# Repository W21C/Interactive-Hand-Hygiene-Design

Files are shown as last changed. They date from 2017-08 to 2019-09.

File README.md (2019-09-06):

2019-09-06: This repository is no-longer being updated, and is out dated. A new more comprehensive version has been released September 2019.

# Interactive Hand Hygiene Design

W21C: http://w21c.org/

ECUAD: http://research.ecuad.ca/healthdesignlab/

## Project Background

This repository contains the hardware and software specifications neccesary to retrofit hand hygiene dispensers to capture real-time, continuous data and display that information with interactive design.  

## Collaboration

Emily Carr University of Art + Design's Health Design Lab developed the original software and hardware to promote hand hygiene compliance through interaction design in collaboration with Vancouver Coastal Health. W21C leveraged the existing technology, and modified the hardware to create networked hand hygiene dispensers to implement onto a medical teaching unit at Foothills Medical Center (Calgary, Alberta), with the goal of promoting hand hygiene compliance. 

## Tech Details

The most recent W21C project uses Xbees embedded into hand hygiene dispensers to track usage of hand hygiene dispensers on a hospital unit. The Xbees communicate with a Processing sketch via an arduino and serial communication.

Software Folder: Processing code for recording and visualizing dispenser use.

Hardware Folder: Specifications for networked hand hygiene dispensers using Xbees and Arduinos, as well as a parts list that includes video terminals and computing. 

## Impact and Efficacy

A Quality Improvement project by W21C at Foothills Medical Center produced results that indicate interaction design successfully increases hand hygiene compliance and that frequency of use of the modified hand hygiene dispensers correlates with hand hygiene compliance. 

## Objectives

Share and promote the improvement and dissemination of this freely available hardware and software, this social innovation demonstrates the potential to increase hand hygiene compliance and innovation in healthcare and everywhere else !

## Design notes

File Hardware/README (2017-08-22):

This folder contains the hardware specifications neccasary to retrofit hand hygiene dispensers for interaction design. 

Fritzing - Fritzing file for the schematic and PCB design

PCB schematics - PCB digram for Transmitters and Receivers for the XBee network

Functional Breakdown - support to build and install the modified hand hygiene dispensers

Parts list - all of the hardware components (i.e., Xbees, arduinos, batterypacks, CPU) used to build wirless Xbee networks 
and display the data on TV monitors. 

Xbee Migration - guide to  assist you with migrating from the XBee/XBee-PRO ZB (S2/S2B) to the XBee/XBee-PRO ZB
(S2C) Through-Hole modules.

Switch Integration - The switch used in the current version was plastered onto the hand hygiene dispenser with sugru. 
Our team would recommend creatively constructing an alternative to our 'switch and sugru' solution. Have fun !

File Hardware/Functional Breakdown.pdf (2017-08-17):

# Functional Decomposition Of Wireless Communication & Display

## Prepared by:

Manas Bhatnagar, MHSc
Based on work done by
Health Design Lab at the Emily Carr Design University

Version: 2.0 (release candidate) Last Updated: 18th Apr 2016

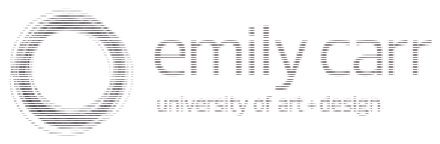
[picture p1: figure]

TV Display

# Concept Level

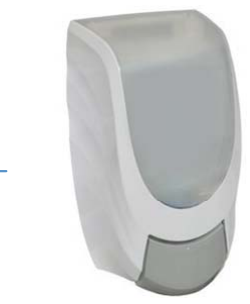
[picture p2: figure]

Mechanical Hand
Sanitizer Pump

# Level 0

Transmitter
(Tx) Receiver (Rx)

Mechanical
Hand Sanitizer
Pump

TV Display

# Level 1

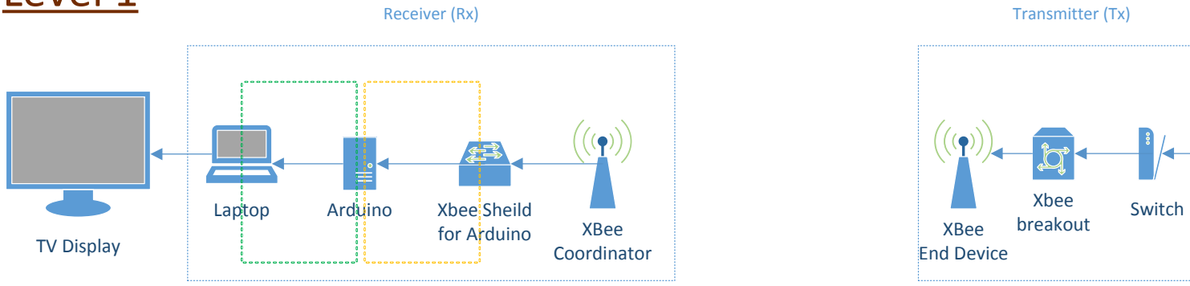
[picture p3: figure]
XBee Coordinator; Laptop; Arduino; TV Display; Xbee Sheild for Arduino; Switch; XBee End Device; Xbee breakout; Receiver (Rx); Transmitter (Tx)

Mechanical
Hand
Sanitizer
Pump

# Level 2 – Detailed Design

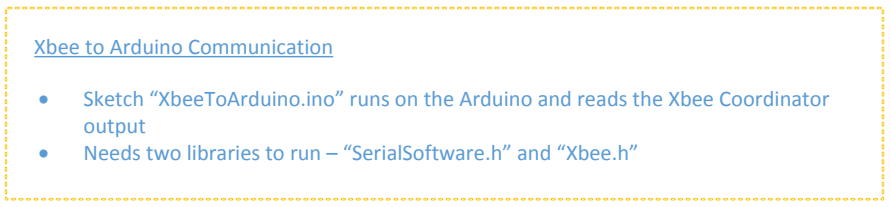
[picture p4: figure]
Xbee to Arduino Communication; output
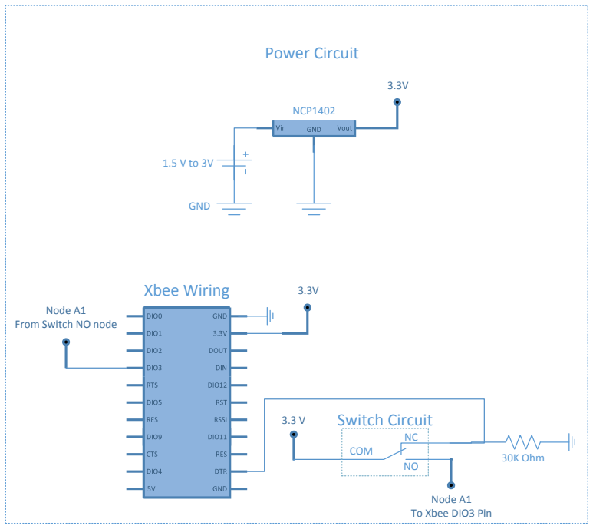
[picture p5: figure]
GND; NCP1402; Power Circuit; Switch Circuit; 30K Ohm; Node A1 To Xbee DIO3 Pin; Xbee Wiring; Node A1 From Switch NO node; COM

- Sketch “XbeeToArduino.ino” runs on the Arduino and reads the Xbee Coordinator
- Needs two libraries to run – “SerialSoftware.h” and “Xbee.h”

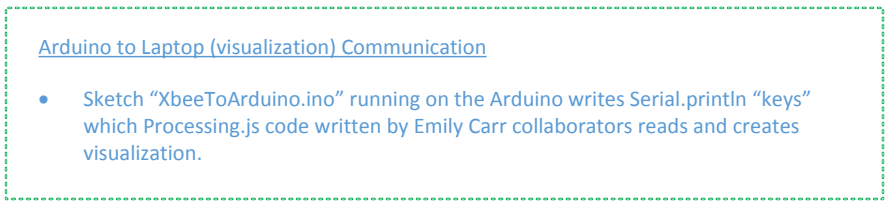
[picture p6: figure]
Arduino to Laptop (visualization) Communication; visualization.

- Sketch “XbeeToArduino.ino” running on the Arduino writes Serial.println “keys” which Processing.js code written by Emily Carr collaborators reads and creates

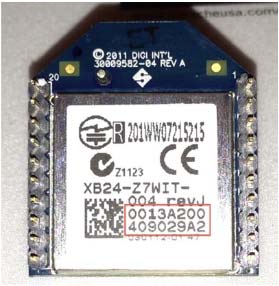
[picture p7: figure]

Figure 1

- Mount Xbee unit onto Explorer USB and connect to a PC via USB.
- Start the XCTU application. Click “Discover Devices” button in the top left corner.
- Click “Next”>”Finish”. Any connect devices should be displayed at this point. Click “Add selected devices”.
- If this is the first time this Xbee is being connected to a computer, then click the “Update firmware” icon. If this Xbee will be used at the receiving end, select “ZigBee Coordinator API”. Else if this Xbee will be used at the transmitting end, select “ZigBee End Device API”. Click “Update”
- Change “PAN ID” to a unique value. All Xbee’s on a network have the same Pan ID.
- If you are configuring an Xbee to be used at the transmitting end, then change the following values,

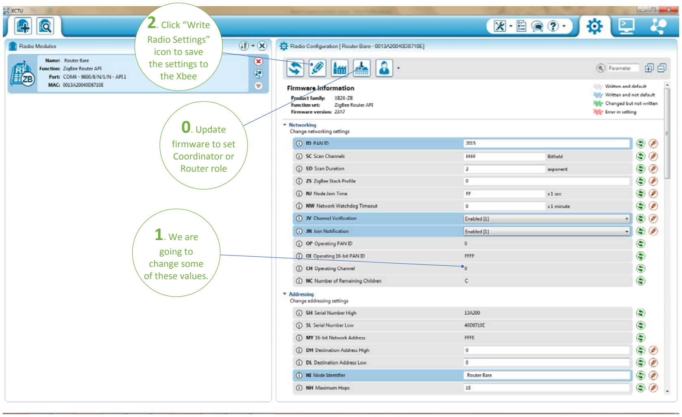
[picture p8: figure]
0. Update; firmware to set Coordinator or Router role; 1. We are; going to change some of these values.; 2. Click “Write; Radio Settings” icon to save the settings to the Xbee

- If you are configuring an Xbee to be used at the receiving end, then change the following values
- Click “Write Radio Settings” icon to save these setting to the Xbee.

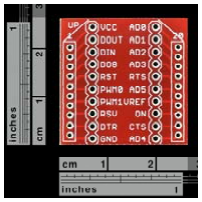
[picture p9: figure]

Figure 2

- Set “JN Join Notification” to Enabled
- Set “NI Node Identifier” to name this particular Xbee.
- Set “PL Power Level” to Lowest [0]
- Set “PM Power Mode” to Boost mode disabled [0]
- Set “SM Sleep Mode” to Pin Hibernate [1]
- Set “SP Cyclic Sleep Period” to AF0
- Set “SN Number of Cycles to power down IO” to FFFF
- Set “SO Sleep Options” to 4
- Set “D3 AD3/DIO3 Configuration” to ADC [2]
- Set “IR IO Sampling Rate” to 190. This makes the Xbee send its state every 400ms. Set it to 3E8 if you want the Xbee to send its state every second. Set it to 1F4 if you want the Xbee to send its state every half second. For other time intervals, use a decimal to hexadecimal calculator to convert time in milliseconds to its hexadecimal representation.
- Set “V+ Supply Voltage High Threshold” to FFFF
- Set “NI Node Identifier” to name this particular Xbee.
- Set “AP _________” to 2
- Set “SP Cyclic sleep period” to AF0
- Set “SN Number of Cycles to power down IO” to FFFF

# XBee

- Many types. We are using the “Xbee ZigBee (2 mW ‐PCB Antenna)” type.
- Each has a unique factory set ID (Figure 1). We need to note these down and identify the ones we configure as coordinators.
- The pins on the Xbee are too close together for prototyping and so we need to use a breakout board to work with it or read it using a USB. We are using the Sparkfun Breakout board for Xbee Module (Figure 2) for this purpose.
- Before the Xbee’s can be used in a network, we need to configure them ‐

# Arduino

- Many types. We are using the “Arduino Uno SMD Rev3” type.
- In addition to the Arduino IDE, you’ll need to ensure that the following libraries are installed in the Arduino IDE –
- Arduino code (“sketch”) XbeeToArduino the code that will need to be changes if any changes or additions are required.
- Once the code is changed, click “Verify” icon to ensure there are no errors.
- If the code successfully compiles, click the “Upload” icon to download the code to the arduino board. This code will run in a loop whenever the arduino has power.
- For troubleshooting, a lot of the commented code can be uncommented and its output can be viewed on the “Serial Monitor” in the Arduino IDE.

Adding a new Xbee to Arduino code so visualization can occur
- After the Xbee is configured appropriately (See section on Xbee), convert the last four digits of the Xbee’s address to decimal format: http://www.binaryhexconverter.com/hex‐to‐decimal‐converter
- Enter this decimal number into the swtich statement as a new case.
- Serial.println(“X”) ‘X’ can range from 1 to 6 depending on what colour of visualization you’d like.
- Compile the code. If Compilation is successful, upload the code to the Arduino.
- SoftwareSerial.h ‐ https://www.arduino.cc/en/Reference/SoftwareSerial
- XBee.h ‐ https://github.com/andrewrapp/xbee‐arduino

# Processing

- Processing.js creates the visualization. Our code runs on the Processing version 2.2.1. Newer versions are available, but I’m not confident that we will not face backwards compatibility issues.
- To change any aspect of the visualization, this is the code that must be changed.
- When any of the code is opened in the Processing IDE, many tabs are created. Relevant tabs might be “Serial” and “Handwashing”.
- Maintain the files/folder structure.
- The original Emily Carr code also does table creation and backend utilization counts. But my recommendation is to recreate all research tracking from scratch in the Arduino code.

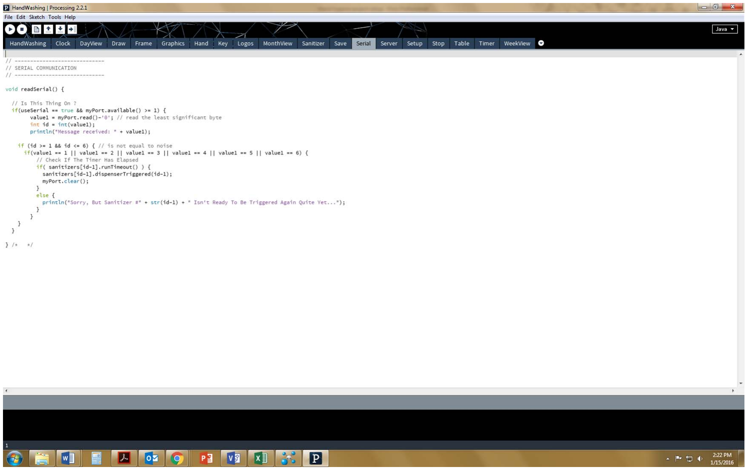
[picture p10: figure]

# Steps to set‐up code on a new computer

- Install Arduino IDE from: https://www.arduino.cc/en/Main/Software
- Once installation is over, start the Arduino IDE. Click Sketch>Include Library>Manage Libraries..
- Plug in the Arduino Board.
- Windows might look for device drivers if this is the first time an Arduino is being connected to the machine. Allow it to do so. It may take several minutes.
- Once device drivers are installed Windows will display a COM port associated with the Arduino. Ex: COM1, COM3, COM6 etc.
- Obtain a bright green USB named HndHygInstl. It contains most of the files needed to make the code run on another machine.
- Copy all the files from this USB on to the computer.
- Open folder “processing‐2.2.1” and run the processing application. If prompted to upgrade version, say no.
- Once the processing application has started (an empty sketch). Close it.
- Go to folder labeled ProcessingCode>Processing>HandWashing. Open file called Setup. (You might have to maximize the window size of the Processing IDE and find the Setup tab)
- In the “if(useSerial == true)” statement, in line 37, change the value of COM# to match the value you noted down from the device manager in previous steps.
- In the ‘Handwashing’ tab, change the Network_Name variable to the correct value, i.e. Network_201#
- Save these changes by clicking File>Save.
- Ensure the Arduino is plugged in. Then turn on a transmitter unit. And Run the Processing code by clicking the play button near the top left corner.
- If all is well, then you should see the black screen of the application start and you can test the system by using the transmitter to create a hand print on the screen
- If asked for permissions to install drivers, say yes.
- In the search bar type “Xbee” and install the Xbee‐Arduino Library by Andrew Rapp (You will need to be connected to the internet for this step)
- Next search for “SoftwareSerial” and ensure that it is installed
- If this is not shown, you can find this information by going to the Control Panel>Hardware and Sound>Device Manager
- Click ‘Ports’ and note the COM# associated with the Arduino board

# Versioning Convention

- 0 for alpha (status)
- 1 for beta (status)
- 2 for release candidate
- 3 for (final) release.

# To‐do List

- GitHub source control for all code
- Add flag for low battery
- Add code to track usage
- Add software filter to reduce false positives
- Periodic polling to ensure all devices are functioning

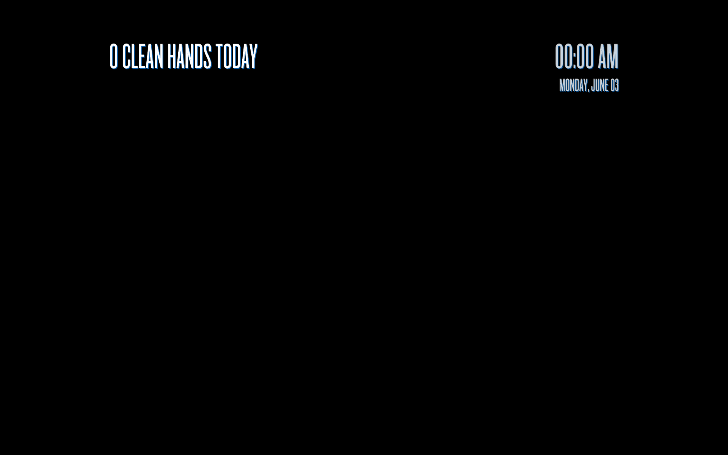
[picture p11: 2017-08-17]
Software/ProcessingCode/Processing/HandWashing/Screenshots/handproject_2013-6-4-0-0-30.PNG

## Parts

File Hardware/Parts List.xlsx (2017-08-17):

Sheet: QI Grant Budget
 | Parts List (per wing)
 |  | Part Name | Specification | Quantity | Price | Product URL
Power |  | AA rechargeable battery | 1.5V | 12 | 51 | Best-buy link (http://www.bestbuy.ca/en-CA/product/energizer-energizer-nh15bp4-4-pack-aa-nimh-rechargeable-batteries-aa-4-nimh/10019056.aspx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)
 |  | Battery holder |  | 6 | $7.74 | http://www.canadarobotix.com/battery-chargers/2-aa-battery-holder-enclosed-with-switch
 |  | 3.3V Transformer | 3.3V step up from 1v to 3V | 6 | $39.54 | http://www.canadarobotix.com/power-regulator/1235-pololu-3-3v-step-up-voltage-regulator-ncp1402 | https://www.sparkfun.com/products/10967
General |  | Headers | Male and Female | 5 | $6.75 | http://www.canadarobotix.com/cables-wires/parts-arduino-stackable-header-r3 http://www.canadarobotix.com/cables-wires/parts-header-female-straight-40 http://www.canadarobotix.com/cables-wires/parts-break-away-header-male-straight-40
 |  | Jumperwires | Red, black and one other colour | 1 | $6.99 | http://www.canadarobotix.com/cables-wires/1162-premium-splittable-jumper-wire-40-pins-m-f-20cm
 |  | Wire | Red, black and one other colour | 1 | $5.99 | http://www.canadarobotix.com/prototyping/140-piece-wire-kit
 |  | Wire Stripper |  | 1 | $15 | http://www.canadiantire.ca/en/pdp/mastercraft-calibrated-wire-stripper-0529938p.html#.Viax4X6rS70
 |  | Solder |  | 1 | $11 | http://www.thesource.ca/estore/Product.aspx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
 |  | Protoboard |  | 6 | $17.94 | http://www.canadarobotix.com/prototyping/1160-protoboard-3x7cm-2-sided
 |  | Breadboard |  | 1 | $4.99 | http://www.canadarobotix.com/solderless-breadboard/830-point-breadboard
 |  | Resistors | 10K Ohm | 6 | $3.54 | http://www.canadarobotix.com/electronic-components/10k-ohm-resistor-1-4w-5
 |  | LEDs |  | 1 | $4.99 | http://www.canadarobotix.com/led-lighting/1698-basic-3mm-led-25x-red
 |  | Plastic Casing |  | 7 | $70.00
 |  | Misc Shipping |  |  | $50.00
Sensors |  | Xbee-ZB | series 2 | 7 | $83.07 | http://www.canadarobotix.com/xbee/digi-xbee-zb-2mw-pcb | https://www.sparkfun.com/products/11217
 |  | Xbee Explorere USB |  | 6 | $197.34 | http://www.canadarobotix.com/xbee-adapters/1230-sparkfun-xbee-explorer-usb | https://www.sparkfun.com/products/11812
 |  | Arduino Uno | SMD R3 | 1 | $26.69 | http://www.canadarobotix.com/arduino-microcontroller/arduino-uno-smd-3 | https://www.sparkfun.com/products/11224
 |  | Sparkfun Xbee Sheild |  | 1 | $21 | https://www.sparkfun.com/products/12847
 |  | On-Off Switch |  | 6 | $24 | http://www.digikey.ca/product-search/en?keywords=SW1068-ND
Display |  | Small Laptop | Must have USB, Display out and decent graphics processor | 1 | $479 | http://www.dell.com/ca/p/inspiron-11-3157-laptop/pd?oc=ni113157_bt_h1403e&model_id=inspiron-11-3157-laptop
 |  | LCD display |  | 1 | $199 | http://www.bestbuy.ca/en-CA/product/insignia-insignia-32-720p-60hz-led-tv-ns-32d220na16-gloss-black-ns-32d220na16/10346767.aspx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
 |  | LCD Display Mount |  | 1 | $99 | http://www.bestbuy.ca/en-CA/product/tyger-claw-tygerclaw-17-37-full-motion-flat-panel-tv-wall-mount-lcd5004blk-lcd5004blk/10200518.aspx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
 |  | HDMI Cable |  | 1 | $4 | http://www.bestbuy.ca/en-ca/product/dynex-dynex-0-9m-3-ft-hdmi-cable-dx-sf115-dx-sf115/10238212.aspx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
 |  |  |  | Total: | $1428.57

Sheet: version 1 Build
 |  | Parts List
 |  |  | Part Name | Specification | Quantity | Price | Product URL
 | Power |  | AA battery | 1.5V | 2 per TXunit | $9.99 | http://www.bestbuy.ca/en-ca/product/energizer-energizer-aa-1-5v-8-pack-batteries-aa-8-pack/38771003.aspx
 |  |  | Battery holder |  | 1 per TX unit | $1.29 | http://www.canadarobotix.com/battery-chargers/2-aa-battery-holder-enclosed-with-switch
 |  |  | 3.3V Transformer | 3.3V step up from 1v to 3V | 1 per TX unit | $13.18 | https://www.sparkfun.com/products/10967 | http://www.canadarobotix.com/power-regulator/1235-pololu-3-3v-step-up-voltage-regulator-ncp1402
 | General |  | Headers | Male and Female | 3,1,1 | $6.75 | http://www.canadarobotix.com/cables-wires/parts-arduino-stackable-header-r3 http://www.canadarobotix.com/cables-wires/parts-header-female-straight-40 http://www.canadarobotix.com/cables-wires/parts-break-away-header-male-straight-40
 |  |  | Jumperwires | Red, black and one other colour | 1 | $6.99 | http://www.canadarobotix.com/cables-wires/1162-premium-splittable-jumper-wire-40-pins-m-f-20cm
 |  |  | Wire | Red, black and one other colour | 1 | $5.99 | http://www.canadarobotix.com/prototyping/140-piece-wire-kit
 |  |  | Protoboard |  | 1 per TX unit | $5.98 | http://www.canadarobotix.com/prototyping/1160-protoboard-3x7cm-2-sided
 |  |  | Resistors | 30K Ohm | 1 per TX unit | $0.15 | https://www.digikey.ca/product-detail/en/stackpole-electronics-inc/CF14JT30K0/CF14JT30K0CT-ND/1830386
 | Sensors |  | Xbee-ZB | series 2 | 2 | $55.38 | http://www.canadarobotix.com/xbee/digi-xbee-zb-2mw-pcb | https://www.sparkfun.com/products/11217 | NOTE: The S2 has been discontinued and is replaced by the S2C - http://ftp1.digi.com/support/documentation/XBee%20ZigBee%20Migration%20Guide.pdf
 |  |  | Xbee Explorere USB |  | 1 | $32.89 | http://www.canadarobotix.com/xbee-adapters/1230-sparkfun-xbee-explorer-usb | https://www.sparkfun.com/products/11812
 |  |  | Arduino Uno | SMD R3 | 1 | $26.69 | http://www.canadarobotix.com/arduino-microcontroller/arduino-uno-smd-3 | https://www.sparkfun.com/products/11224
 |  |  | Sparkfun Xbee Sheild |  | 1 | $21 | https://www.sparkfun.com/products/12847
 |  |  | Switch |  | 1 per TX unit | $4.5 | https://www.digikey.ca/product-detail/en/omron-electronics-inc-emc-div/SS-5GL2T/SW873-ND/369897
 | Display & Computing |  | Laptop or Computer |  | 1 | $350 | Requirements: USB, HDMI display out, Windows OS, decent graphics processor
 |  |  | LCD Display |  | 1 | $200 | Requirements: HDMI display input
 |  |  | LCD Display Mount |  | 1 | $25 | Wall mount
 |  |  | HDMI Cable |  | 1 | $25 | Length dependent on PC - Display distance
 | Tools |  | Wire Stripper |  | 1 | $14.99 | http://www.canadarobotix.com/soldering-tools/1892
 |  |  | Soldering Iron |  | 1 | $43.59 | http://www.canadarobotix.com/soldering-tools/1898
 |  |  | Solder |  | 1 | $10.59 | http://www.canadarobotix.com/soldering-tools/solder-lead-free-100-gram-spool
 |  |  | Sponge |  | 1 | 7.29 | http://www.canadarobotix.com/soldering-tools/2118
` |  |  | Voltmeter/Multimeter |  | 1 | $19.69 | http://www.canadarobotix.com/measurement-equipment/1476-sparkfun-digital-multimeter-basic
 |  |  | Breadboard |  | 1 | $3.99 | http://www.canadarobotix.com/solderless-breadboard/400-point-breadboard-standard
 |  |  |  |  | Total | 190.78

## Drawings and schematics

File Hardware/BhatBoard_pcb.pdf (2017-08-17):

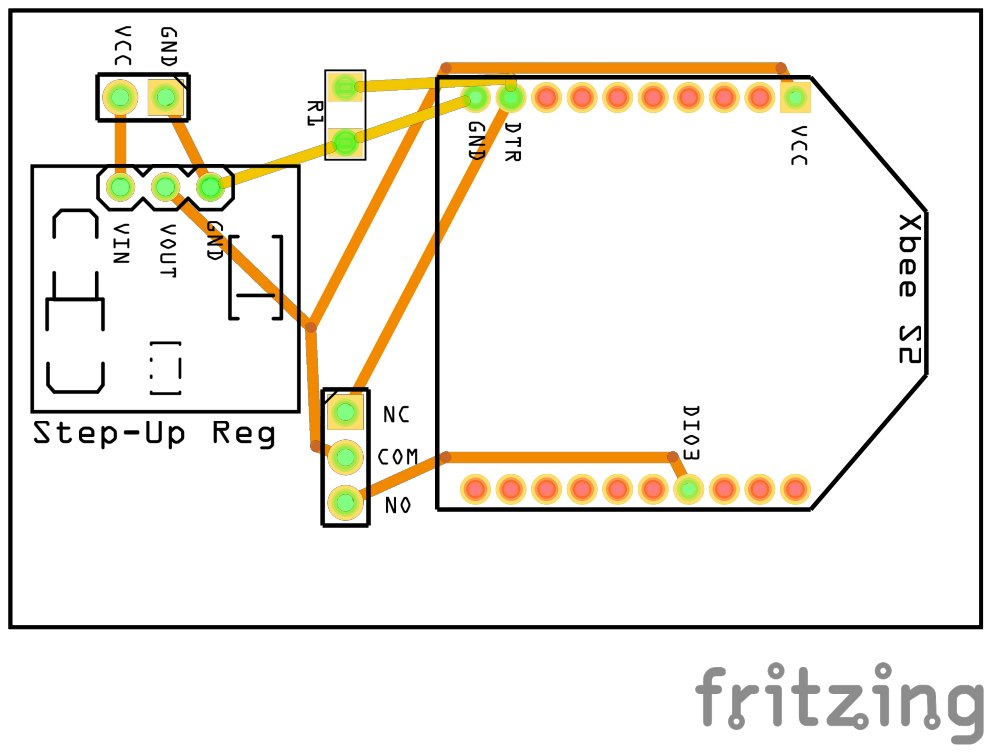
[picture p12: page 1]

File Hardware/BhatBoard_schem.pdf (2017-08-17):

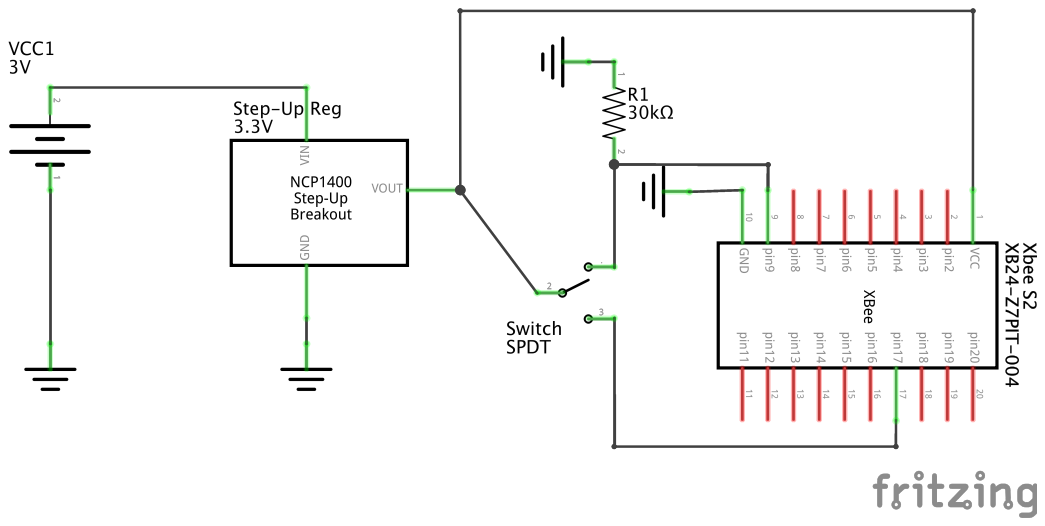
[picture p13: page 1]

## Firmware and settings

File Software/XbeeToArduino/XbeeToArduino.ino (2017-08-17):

#include <XBee.h>
#include <SoftwareSerial.h>

// Setup pin definitions for XBee shield
uint8_t recv = 2;
uint8_t trans = 3;
SoftwareSerial soft_serial(recv, trans);

// Instantiate an instance of the XBee library
XBee xbee = XBee();

// Instantiate an instance of the IO sample class
ZBRxIoSampleResponse ioSample = ZBRxIoSampleResponse();

void setup() {
  Serial.begin(9600);
  while (!Serial); // Leonardo boards need to wait for Serial to start
  soft_serial.begin(9600);
  xbee.setSerial(soft_serial);
}

// Get address and print it
void get_address(ZBRxIoSampleResponse *ioSample) {
//  Serial.print("Received data from address: ");
//  Serial.print(ioSample->getRemoteAddress64().getMsb(), HEX);
//  Serial.print(ioSample->getRemoteAddress64().getLsb(), HEX);
//  Serial.println("");
}

// Get voltage at signal pin DI03 and print it
void get_temperature(ZBRxIoSampleResponse *ioSample) {
  int Address_LSB = (ioSample->getRemoteAddress64().getLsb());
  String Address = String(Address_LSB, HEX);
     //Serial.print("Last four didgits of HEX Address: ");
     //Serial.print(Address); Serial.println(" ");
     //Serial.print("Decimal number to use in Switch Statement: ");
  //Serial.print(Address_LSB); Serial.println(" ");Serial.println(" ");
  //int Packet_length = (ioSample->getPacketLength());
  
  float adc_data = ioSample->getAnalog(3);
  float temperatureC = ((adc_data * 1200.0 / 1024.0) / 1000.0);
  
  int ref = xbee.getResponse().getFrameData()[17]<<8;
  ref += xbee.getResponse().getFrameData()[18]<<8;
  float volts = (float(ref) * float(1200.0 / 1024.0))/1000.0;

  switch (Address_LSB) {
    case 18975:
     if (temperatureC != 0) {
       if(volts == 3.3){ Serial.println("A");}
       else{Serial.println("B");}
     }
      //Serial.println(temperatureC);
      break;

    case 19004:
      if (temperatureC != 0) {
       if(volts == 3.3){ Serial.println("C");}
       else{Serial.println("D");}
      }
      break;

    case 26410:
     if (temperatureC != 0) {
       if(volts == 3.3){ Serial.println("E");}
       else{Serial.println("F");}
     }
      break;

     case 19807:
     if (temperatureC != 0) {
       if(volts == 3.3){ Serial.println("G");}
       else{Serial.println("H");}
     }
      break;

     case 44402:
     if (temperatureC != 0) {
       if(volts == 3.3){ Serial.println("I");}
       else{Serial.println("J");}
     }
     break;

    case 44397:
     if (temperatureC != 0) {
       if(volts == 3.3){ Serial.println("K");}
       else{Serial.println("L");}
     }
      //Serial.println(temperatureC);
     break;

    case 44399:
     if (temperatureC != 0) {
       if(volts == 3.3){ Serial.println("M");}
       else{Serial.println("N");}
     }
      //Serial.println(temperatureC);
      break;
       
    default:
      Serial.println("default break");
      break;
  }

  //Serial.print(temperatureC);
  // Serial.print("V; ");

}


// Get supply voltage and print it
void get_supply_voltage() {
  //##################//
//  Serial.print("Supply voltage is");
//  int ref = xbee.getResponse().getFrameData()[17]<<8;
//  ref += xbee.getResponse().getFrameData()[18]<<8;
//////  Serial.println(ref);
//  float volts = (float(ref) * float(1200.0 / 1024.0))/1000.0;
//  Serial.print(" = ");
//  Serial.print(volts);
//  Serial.println("V.");
//
// Serial.print("packet length is ");
// Serial.println(ioSample.getPacketLength(), DEC);
//
//   // this is the actual data you sent
//    Serial.println("Received Data: ");
//    for (int i = 0; i < ioSample.getDataLength(); i++) {
//    Serial.print(ioSample.getData()[i], HEX);
//    Serial.print(' ');}
}

void loop() {
  //attempt to read a packet
  xbee.readPacket();
  if (xbee.getResponse().isAvailable()) {
    // got something
    if (xbee.getResponse().getApiId() == ZB_IO_SAMPLE_RESPONSE) {
      // Get the packet
      xbee.getResponse().getZBRxIoSampleResponse(ioSample);
      // Read and display data
      //Serial.print("IO Sample received!");
      get_address(&ioSample);
      get_temperature(&ioSample);
      get_supply_voltage();
    }
    else {
      //Serial.print("Expected I/O Sample, but got ");
      //Serial.print(xbee.getResponse().getApiId(), HEX);
    }
  } else if (xbee.getResponse().isError()) {
    Serial.print("Error reading packet. Error code: ");
    Serial.println(xbee.getResponse().getErrorCode());
  }
}

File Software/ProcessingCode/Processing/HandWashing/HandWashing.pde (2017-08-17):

/*
 HandWashing Program
 by Haig Armen & Jesse Scott
 Emily Carr University of Art + Design | www.ecuad.ca
 v 2.0
*/ 

// -----------------------------
// IMPORTS
// -----------------------------

import processing.serial.*;
import java.awt.Frame;
import megamu.shapetween.*;
import ddf.minim.* ;

import java.io.File;
import java.util.Date;
import java.text.DateFormat;
import java.text.SimpleDateFormat;
import java.util.Calendar;
import java.util.GregorianCalendar;
import java.awt.event.KeyEvent;

// -----------------------------
// DECLARATIONS
// -----------------------------

Serial myPort;

ArrayList hands;
TheHand tempHand; 
Sanitizer[] sanitizers = new Sanitizer[7];

PFont large, medium, small;
PImage eculogo;
PImage vchlogo;
PShape handImg;

Table dailyTable, weeklyTable, monthlyTable, yearlyTable;

Table w21ctable= new Table();
int numReadings = 50; //keeps track of how many readings you'd like to take before writing the file. 
int readingCounter = 0; //counts each reading to compare to numReadings. 
String pumpName;
String fileName;
String Network_Name = "Network_2016";
String SerialIn; 
int batteryFlag = 1;

Tween anim;

Minim minim;
AudioSample au_player;
AudioSample[] samples = new AudioSample[7];

Calendar calendar;
java.util.Date date;


// -----------------------------
// GLOBAL VARIABLES
// -----------------------------

// Display State
int halfTimeOut = 5;
int fullTimeOut = 15;
int drawState = 1;
int subDrawState = 1;
boolean drawHands = true;

// Hand Counts
int allHandsThisHour  = 0;
int allHandsThisDay   = 0;
int allHandsThisWeek  = 0;
int allHandsThisMonth = 0;
int allHandsThisYear  = 0;

int numHandsThisHour[]   = new int[7];
int numHandsThisDay[]   = new int[7];
int numHandsThisWeek[]  = new int[7];
int numHandsThisMonth[] = new int[7];
int numHandsPerDayThisMonth[] = new int[31];
int numHandsPerDayThisWeek[] = new int[7];
int numHandsThisYear[]  = new int[7]; 

// Daily Table
int totalRow = 7;
int totalCol = 25;

int unitColumn = 0;
int dayColumn = 1;
int weekColumn = 2;
int monthColumn = 3;


// Colours
int bgColor = 0;

color[] palette = {
  color(255, 245, 0, 201),    // Yellow
  color(255, 0, 153, 201),   // Magenta
  color(102, 255, 0, 201),    // Green
  color(0, 153, 255, 201),  // Blue
  color(204, 0, 255, 201),  // Purple
  color(255, 102, 0, 201),   // Orange
  color(245,51,71,201)
};
  
int colorNumber = 0;
int newColor;
color color1 = color(8, 90, 166);
color unitColors[] = new color[6];

color chartColor = color(255, 0, 255);       // Magenta
color dropShadowColor = color(7, 89, 164);   // PSD
color textColor = color(255, 255, 255);
  
// XY
int newX = width/2;
int newY = height/2;
int prevX = width/2;
int prevY = height/2;

// Time / Date / Text / Label Position
int datePositionX, datePositionY;
int timePositionX, timePositionY;
int textPositionX, textPositionY;

int dailyLabelPositionX, dailyLabelPositionY;
int weeklyLabelPositionX, weeklyLabelPositionY;
int monthlyLabelPositionX, monthlyLabelPositionY;

// Text Size
int countTextSize = 96;
int dateTextSize = 96;
int dailyTextSize = 48;
int weeklyTextSize = 48;
int monthlyTextSize = 48;

// Labels
String dailyLabel;
String weeklyLabel;
String monthlyLabel;

// Chart
int baseLineX, baseLineY;
int divStartX, divEndX;
int divOneY, divTwoY, divThreeY;

// Time
String theHour;
String theMin;
String theSec;
String theMeridiem;
String time;

// Date
String theDate;
String theYear;
String theMonth;
String theDay;
  
// Timer
int start;
int count = 0;
int tempSec = 0;
int tempMin = 0;
int lastMin = 0;
int maxTempCount = 600; 
int maxVerticalHands = 30;

// Serial
short portIndex = 1;
char HEADER = 'H';
int value1, value2;
boolean useSerial = true;

float a = 2.5, b = 3.144;
int x = width/2, y = height/2;
 
// Opacity
int op1 = 65;







 
